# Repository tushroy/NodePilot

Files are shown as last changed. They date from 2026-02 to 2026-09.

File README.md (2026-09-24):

NodePilot Logo
# NodePilot – CM108-Based AllStarLink Radio Interface  
NodePilot is a compact, reliable, and isolated **AllStarLink radio interface** based on the CM108 audio USB chipset by **S21TIP**.

This project was designed for both personal use and small-scale production, with a focus on audio quality, RF robustness, and hardware protection.

Channel Driver to used with ASL3: Simpleusb

The complete KiCad schematic, PCB (Work-in-progress), and design files are publicly available under the **CC-BY-SA-4.0** license.

Notes: If you are using buck converters to power Raspberry Pi boards, make sure the switching frequency is greater than 1 MHz for clean audio interfacing. Low-cost converters are often a significant source of RFI, although this circuit can eliminate most of it.

---

## 🔧 Features

✔️ CM108 Frontend Protection  
✔️ Full Audio Isolation  
✔️ Compact & Modular  
✔️ Open Hardware  

---

## 𖤓 Schematic

NodePilot Schematic

---

## 📐 PCB

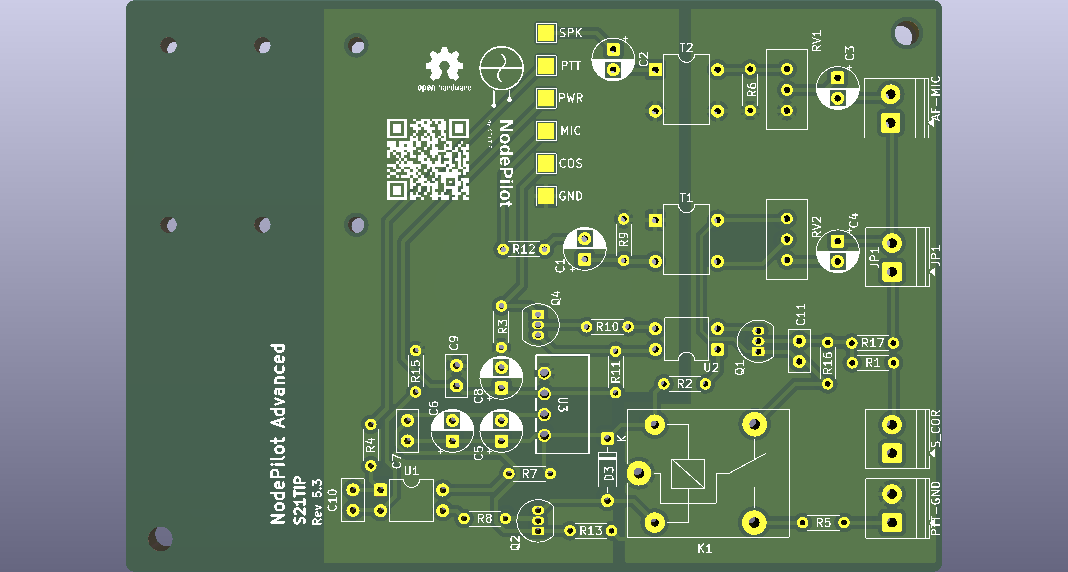
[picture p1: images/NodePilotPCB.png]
NodePilot PCB


---

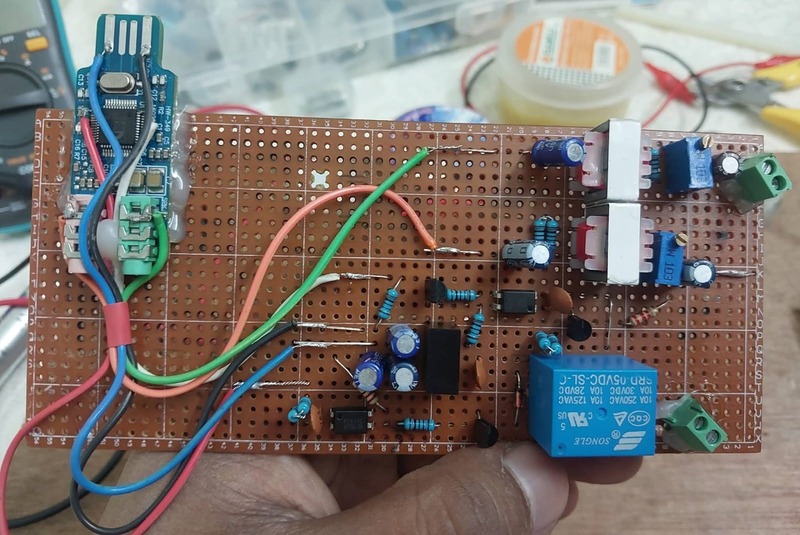
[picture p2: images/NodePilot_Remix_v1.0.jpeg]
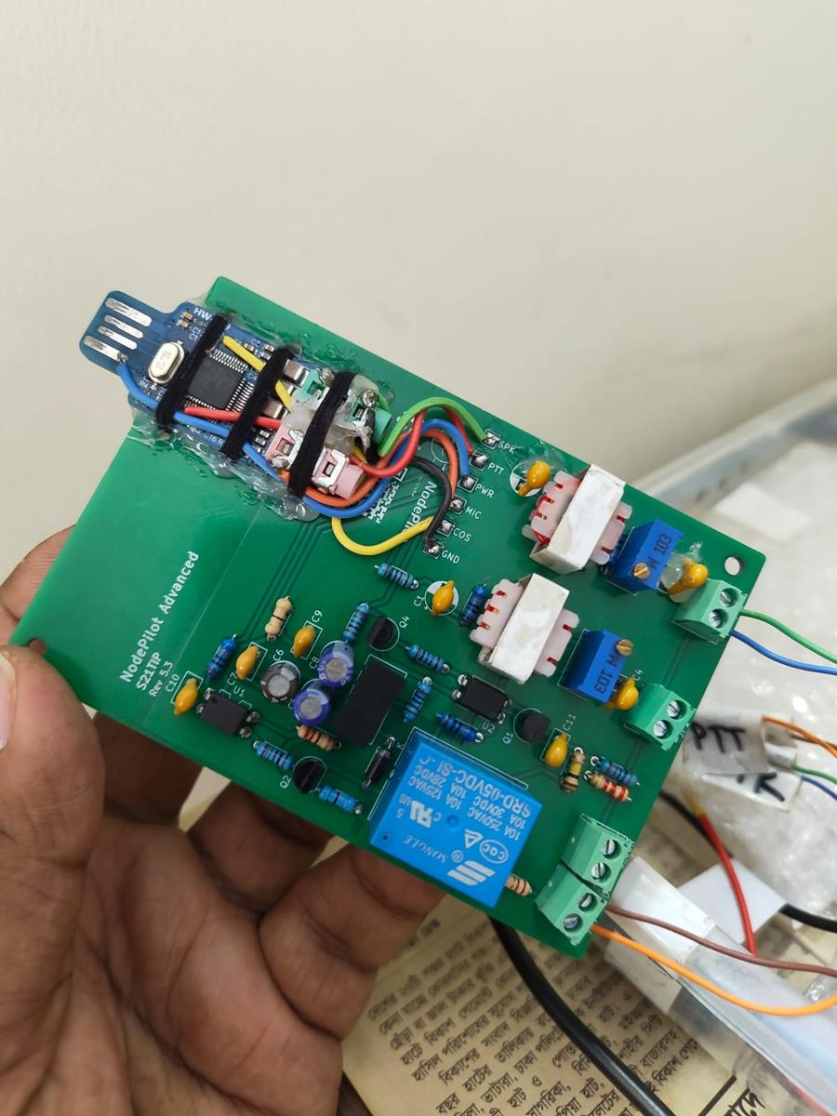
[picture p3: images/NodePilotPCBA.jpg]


---

## 📜 License

This project is released under the **Creative Commons Attribution-ShareAlike 4.0 International (CC-BY-SA-4.0)** license.  
You are free to remix, adapt, and build upon the design, even commercially, as long as you credit the author and share derivative works under the same license.

---

## 📡 Author  
**Tushar Roy – S21TIP**

If you improve the design or build your own version, feel free to open an Issue or Pull Request!

---

## 🌐 Links

### 🔗 QRZ Page  
https://www.qrz.com/db/S21TIP

### 🔗 Radiosanda FB Page  
https://www.facebook.com/share/1FPaPZSuz1/

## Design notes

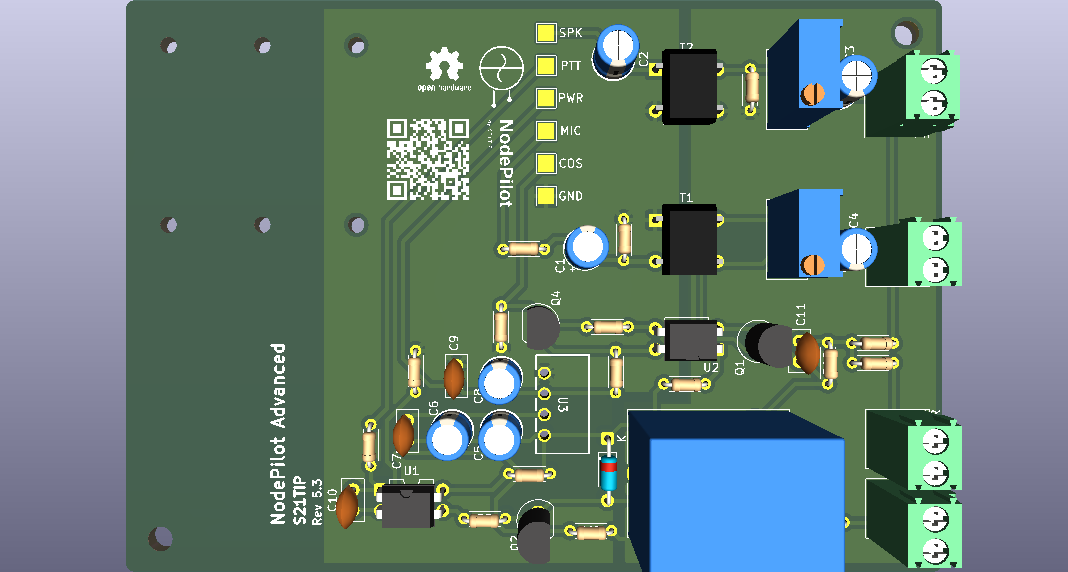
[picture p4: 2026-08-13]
images/NodePilotPCB2.png

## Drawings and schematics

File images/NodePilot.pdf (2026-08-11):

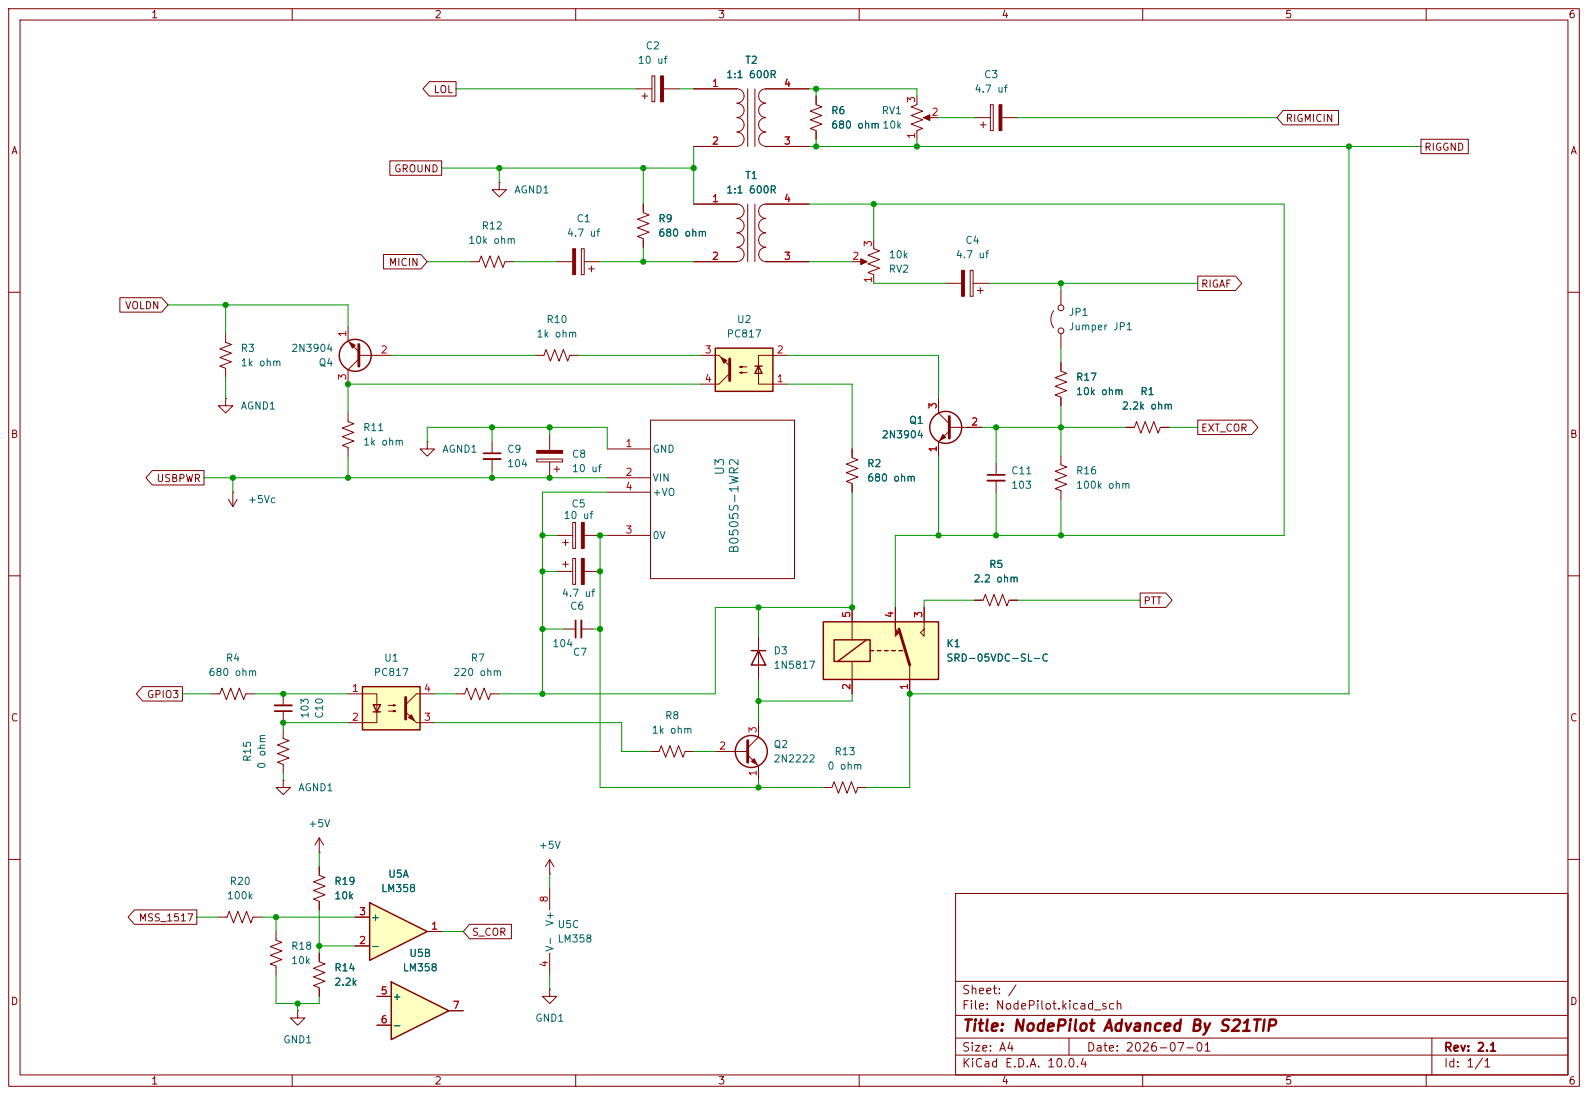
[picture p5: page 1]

Sheet: /
File: NodePilot.kicad_sch
Title: NodePilot Advanced By S21TIP

Size: A4 | Rev: 2.1
KiCad E.D.A. 10.0.4 | Id: 1/1

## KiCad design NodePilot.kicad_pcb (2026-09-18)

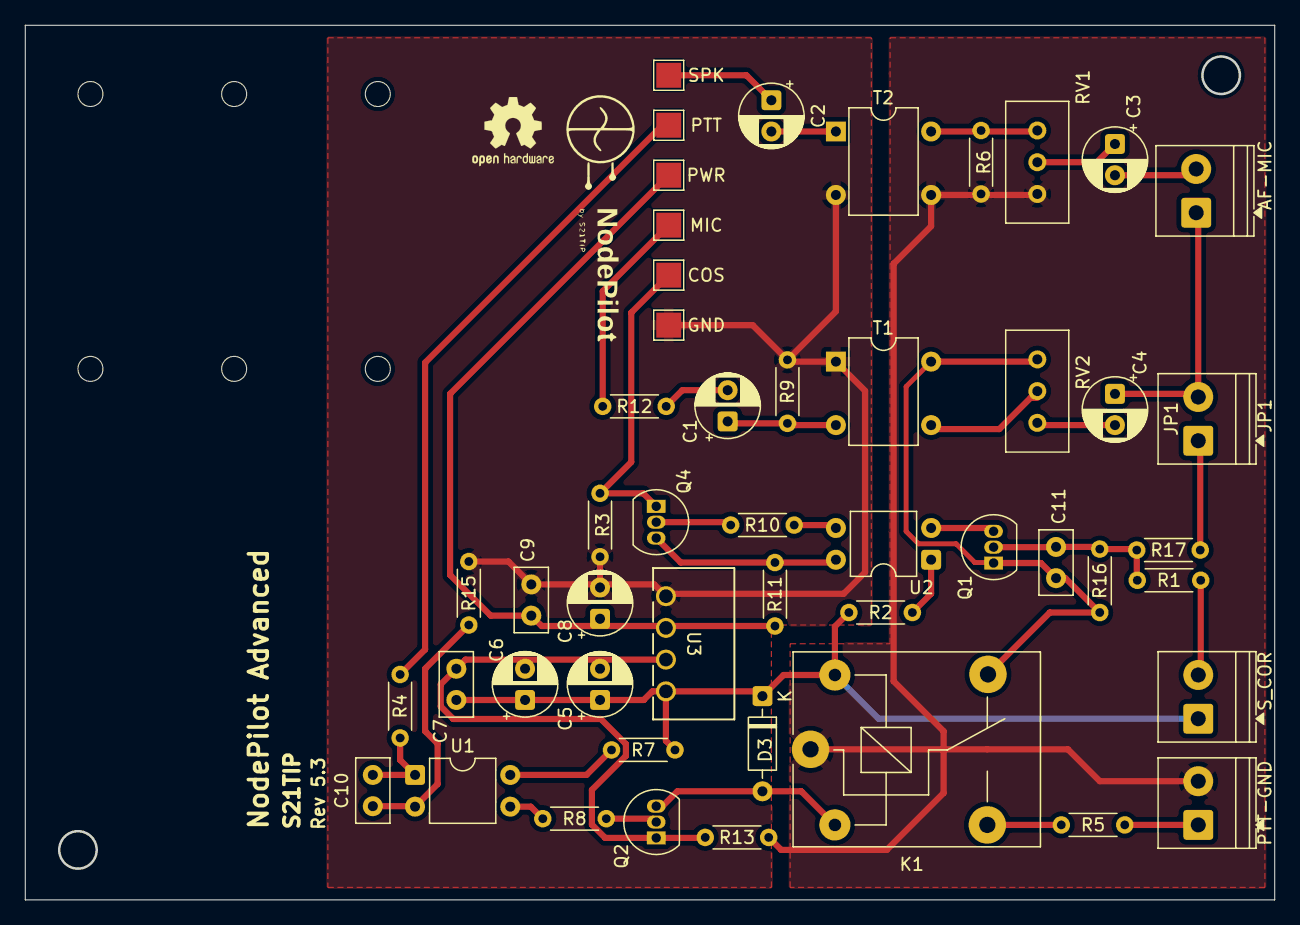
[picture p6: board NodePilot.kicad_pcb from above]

Board: 2 copper layers, 100.0 x 70.0 mm, 40 parts (0 on the bottom side), 29 nets.

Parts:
C1, C3, C4, C6: 4.7 uf; CP_Radial_D5.0mm_P2.50mm
C2, C5, C8: 10 uf; CP_Radial_D5.0mm_P2.50mm
C7, C9: 104; C_Disc_D5.0mm_W2.5mm_P2.50mm
C10, C11: 103; C_Disc_D5.0mm_W2.5mm_P2.50mm
D3: 1N5817; D_DO-35_SOD27_P7.62mm_Horizontal
JP1: JP1; TerminalBlock_Phoenix_PT-1,5-2-3.5-H_1x02_P3.50mm_Horizontal
K1: SRD-05VDC-SL-C; Relay_SPDT_SANYOU_SRD_Series_Form_C
Q1, Q4: 2N3904; TO-92_Inline
Q2: 2N2222; TO-92_Inline
R1: 2.2k ohm; R_Axial_DIN0204_L3.6mm_D1.6mm_P5.08mm_Horizontal
R2, R4, R6, R9: 680 ohm; R_Axial_DIN0204_L3.6mm_D1.6mm_P5.08mm_Horizontal
R3, R8, R10, R11: 1k ohm; R_Axial_DIN0204_L3.6mm_D1.6mm_P5.08mm_Horizontal
R5: 2.2 ohm; R_Axial_DIN0204_L3.6mm_D1.6mm_P5.08mm_Horizontal
R7: 220 ohm; R_Axial_DIN0204_L3.6mm_D1.6mm_P5.08mm_Horizontal
R12, R17: 10k ohm; R_Axial_DIN0204_L3.6mm_D1.6mm_P5.08mm_Horizontal
R13, R15: 0 ohm; R_Axial_DIN0204_L3.6mm_D1.6mm_P5.08mm_Horizontal
R16: 100k ohm; R_Axial_DIN0204_L3.6mm_D1.6mm_P5.08mm_Horizontal
RV1, RV2: 10k; Potentiometer_Bourns_3296W_Vertical
T1, T2: 1:1 600R; Diode_Bridge_DIP-4_W7.62mm_P5.08mm
U1, U2: PC817; DIP-4_W7.62mm
U3: B0505S-1WR2; B0505S-1WR2_MNS

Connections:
GROUND: C8.2, C9.1, R3.2, R9.1, R15.1, T1.1 (AA), T2.2 (AB), U3.1 (GND)
unnamed: C1.2, R12.2
unnamed: C3.1, RV1.2
unnamed: C4.2, RV2.1
unnamed: C10.1, R15.2, U1.2
unnamed: C10.2, R4.2, U1.1
unnamed: D3.2 (A), K1.2, Q2.3 (C)
unnamed: C5.1, C6.1, C7.1, D3.1 (K), K1.5, R2.2, R7.2, U3.4 (+VO)
unnamed: JP1.1 (A), R17.1
unnamed: K1.3, R5.1
unnamed: C11.1, Q1.2 (B), R1.1, R16.1, R17.2
unnamed: Q1.3 (C), U2.2
unnamed: C11.2, K1.4, Q1.1 (E), R16.2, RV2.3, T1.4 (SB)
unnamed: Q2.2 (B), R8.2
unnamed: C5.2, C6.2, C7.2, Q2.1 (E), R13.1, U3.3 (0V)
unnamed: Q4.2 (B), R10.1
unnamed: Q4.3 (C), R11.1, U2.4
unnamed: R2.1, U2.1
unnamed: R7.1, U1.4
unnamed: R8.1, U1.3
unnamed: R10.2, U2.3
unnamed: C1.1, R9.2, T1.2 (AB)
unnamed: RV2.2, T1.3 (SA)
unnamed: C2.2, T2.1 (AA)
unnamed: R6.1, RV1.3, T2.4 (SB)
RIGAF: C4.1, JP1.2 (B)
RIGGND: K1.1, R6.2, R13.2, RV1.1, T2.3 (SA)
USBPWR: C8.1, C9.2, R11.2, U3.2 (VIN)
VOLDN: Q4.1 (E), R3.1

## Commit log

2025-12-13 version 3.2
    [NodePilot.kicad_sch]
2025-12-17 drafted for Relay coil + audio ground coupling #2
    [NodePilot.kicad_sch]
2025-12-17 draft 2
    [NodePilot.kicad_sch]
2025-12-18 fix for issue #2
    [NodePilot.kicad_sch]
2025-12-27 version 5.1
    [NodePilot.kicad_sch]
2026-01-24 Remix v1.0
    [NodePilot.kicad_sch]
2026-01-24 NodePilot Remix v1.0
    [NodePilot.kicad_sch]
2026-01-29 cosmetic change
    [NodePilot.kicad_sch]
2026-02-19 ver 1.1
    [NodePilot.kicad_sch]
2026-02-23 audio stability
    [NodePilot.kicad_sch]
2026-06-21 kicad 10
    [NodePilot.kicad_sch]
2026-06-28 3904 load
    [NodePilot.kicad_sch]
2026-07-01 NodePilot Advanced
    [NodePilot.kicad_sch]
2026-07-07 3904 hardware config error
    [NodePilot.kicad_sch]
2026-07-16 Develop (#6)
    * cap values for af dc blocking filtering
    * big update
    * github image
    * plot fix
    * small change in revert
    * reduce filter capacitor
    * for audio stability
    * protection resistor value reduce
    * protection resistor value
    ---------
    [NodePilot.kicad_sch]
2026-07-27 NodePilot Advance prerelease (#7)
    * node pilot advanced
    * reducing noise while only PTT is pressed.
    * correct v level
    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
    [NodePilot.kicad_sch]
2026-07-28 reduce ptt protection resistor to 2.2 ohm
    [NodePilot.kicad_sch]
2026-08-11 NodePilot PCB (#8)
    NodePilot PCB
    [NodePilot-B_Cu.gbl, NodePilot-B_Mask.gbs, NodePilot-B_Paste.gbp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]
2026-08-12 fixing the transformer footprint
    [NodePilot-B_Cu.gbl, NodePilot-B_Mask.gbs, NodePilot-B_Paste.gbp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]
2026-08-12 board size fix
    [NodePilot-B_Cu.gbl, NodePilot-B_Mask.gbs, NodePilot-B_Paste.gbp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]
2026-08-13 footprint fix
    [NodePilot-B_Cu.gbl, NodePilot-B_Mask.gbs, NodePilot-B_Paste.gbp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]
2026-08-13 GP introduced
    [NodePilot-B_Cu.gbl, NodePilot-B_Mask.gbs, NodePilot-B_Paste.gbp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]
2026-08-13 fix for GP zones
    [NodePilot-B_Cu.gbl, NodePilot-B_Mask.gbs, NodePilot-B_Paste.gbp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]
2026-09-18 power connection trace
    [NodePilot-B_Cu.gbl, NodePilot-B_Mask.gbs, NodePilot-B_Paste.gbp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]
